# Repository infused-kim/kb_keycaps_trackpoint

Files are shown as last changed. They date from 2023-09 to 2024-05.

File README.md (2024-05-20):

# Scripts to cut TrackPoint holes into keyboard keycaps

These scripts allow you to generate keycaps with a cutout for a TrackPoint.

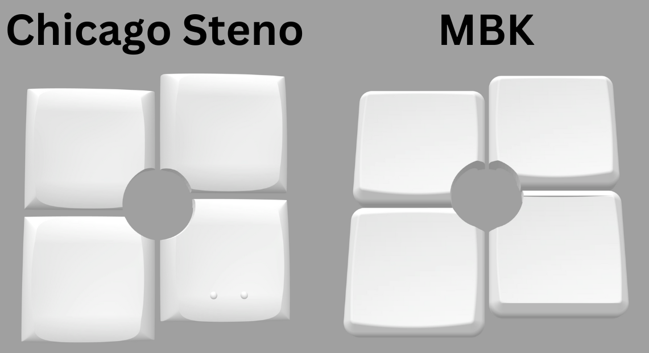
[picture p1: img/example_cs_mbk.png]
Chicago Steno and MBK keycaps with TrackPoint cutout


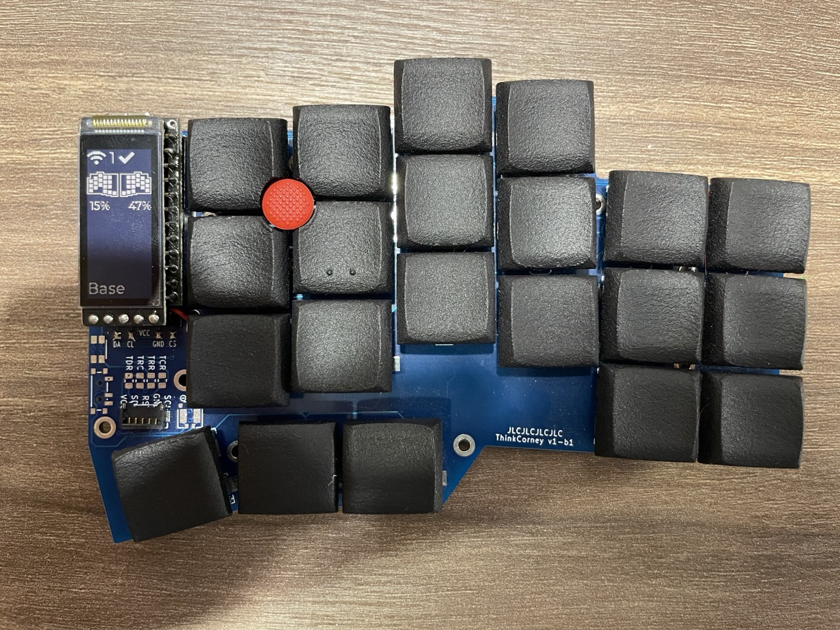
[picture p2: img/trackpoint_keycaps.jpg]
Printed Keycaps


Currently, Chicago Stenographer and MBK keycaps are supported, but it's trivial to add other models as long as you have the stl files.

The generated STLs are sprued and optimized for printing at JLCPCB:

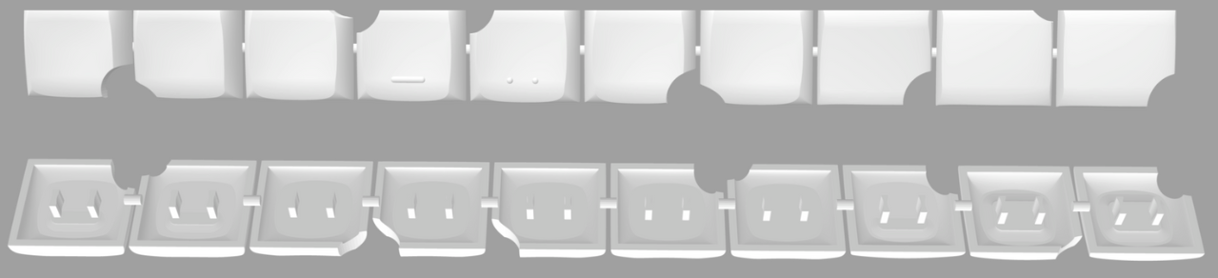
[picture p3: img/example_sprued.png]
Sprued keycaps


This repo was inspired by the awesome idea and work of [wolfwood's printed-keycap-mods](https://github.com/wolfwood/printed-keycap-mods).

However, their code didn't support MBK and is optimized for DIY printing with FDM rather than JLCPCB.

## 1. Table of Contents <!-- omit from toc -->

- [1. Printing / Ordering](#1-printing--ordering)
  - [1.1. How to download the STLs and which files to use](#11-how-to-download-the-stls-and-which-files-to-use)
  - [1.2. How to order on JLCPCB](#12-how-to-order-on-jlcpcb)
  - [1.3. How to print them yourself](#13-how-to-print-them-yourself)
- [2. Using the scripts](#2-using-the-scripts)
  - [2.1. How to generate your own keycaps](#21-how-to-generate-your-own-keycaps)
  - [2.2. How to fix large STL file sizes](#22-how-to-fix-large-stl-file-sizes)
  - [2.3. How to adjust the stagger](#23-how-to-adjust-the-stagger)
  - [2.4. How to adjust the key spacing](#24-how-to-adjust-the-key-spacing)
  - [2.5. How to add a new keycap type](#25-how-to-add-a-new-keycap-type)
- [3. Related Resources \& Projects](#3-related-resources--projects)
- [4. License](#4-license)

## 1. Printing / Ordering

### 1.1. How to download the STLs and which files to use

Go to the [releases section](releases) and download the STL files.

You can find combined STLs that contain all the variations you might need in the `./combined/` folder.

The published files are generated for choc-spaced boards with a stagger of 2.375 (what the corne uses). You can follow the instructions below to generate keycaps with customized spacing and stagger.

Chicago Stenographer has many different variations of keycaps. To understand which ones to use and what the differences are, [check out my fork of those keycaps](https://github.com/infused-kim/kb_keycaps_chicago_stenographer).

There you will also find the rest of the keycaps needed to print a full set or you can buy a full set from the creator [at asymplex.xyz](https://www.asymplex.xyz).

MBK keycaps are not really meant to be printed, so you should buy the rest of the keycaps from one of the many vendors that sell them.

### 1.2. How to order on JLCPCB

* Upload the STL model
* Select 3D Technology: `MJF (Nylon)`
* Select Material: `PA12-HP Nylon`
* Optionally select Surface Finish: `Add - Dyeing - Dyed Black` to get black keycaps.
  * Without this they will be a "textured gray"
* Make sure to select the correct Quantity

The two combined sets should cost $5.05.

### 1.3. How to print them yourself

I have no clue... I don't own a 3D printer and this is my first 3D modeling project.

You can check out [wolfwood's printed-keycap-mods](https://github.com/wolfwood/printed-keycap-mods) as his project is optimized for FDM printing.

You may also find [these instructions](https://www.printables.com/model/158865-chicago-steno-low-profile-ergo-keycaps) valuable.

Perhaps you can modify the files here manually.

I would also be happy to accept a PR that generates STLs that are optimized for printing yourself.

## 2. Using the scripts

### 2.1. How to generate your own keycaps

* Install OpenSCAD
  * The [snapshot version](https://openscad.org/downloads.html#snapshots) is recommended for performance reasons
  * If it crashes, [try an older version of the snapshot](https://files.openscad.org/snapshots/)
* Set up the dev environment
  * Adjust the Makefile with the path to your OpenSCAD installation
* Run the keycap generator
  * Run `make help` to see all available targets
  * Or run `make` to build everything

You can also open the individual files in the OpenSCAD GUI if you prefer.

### 2.2. How to fix large STL file sizes

OpenSCAD generates files with very big sizes and JLCPCB only allows files to be up to 80mb.

To fix this Fusion360 (The free version is fine)...

* Create a new file
  * Do not open the STL directly. That will mess up the units
* Select the `Mesh` tab on the top toolbar
* Select `Insert Mesh` (first icon)
  * Select the STL file and click `Open`
  * This will load the model and show a `Insert Mesh` window
  * Make sure the `Unit Type` is set to `Millimeter`
  * Press the `OK` button
* Save it to the cloud
* Use `File -> Export` to export the file as STL again

The file size should now be under 80 MB.

### 2.3. How to adjust the stagger

You can adjust the stagger by running `make STAGGER=5.5`.

### 2.4. How to adjust the key spacing

By default, keycaps are cut using the choc spacing, but you can change the spacing to mx by running `make PROFILE=mx`.

You can also specify custom values by running `make PROFILE=custom SPREADX=20 SPREADY=22`.

But keep in mind that this doesn't change the size of the keycaps. It only changes the distance at which they are placed before cutting.

### 2.5. How to add a new keycap type

#### 3.5.1. Add the keycap STLs <!-- omit from toc -->

First, add the keycap STLs to the `./keycaps/` directory.

#### 3.5.2. Figure out the positioning offset of the keycaps <!-- omit from toc -->

The cutter expects the keycaps to be centered around the origin, but many keycap designers offset the keys slightly.

You can open the files in Fusion 360 or another 3D editor to figure out the offsets.

#### 3.5.3. Create the SCAD file <!-- omit from toc -->

Then duplicate the `src/gen_mbk.scad` file. Make sure the file name starts with `gen_` or the Makefile won't recognize it.

Adjust the keycap path and add the necessary positional adjustments.

For example, the MBK homing keycap was centered at `x: -23` and `y: 0`. So we moved it to the origin with:

```scad
// Keycap array: stl path, translate adjustment, rotation, mirror
mbk_1u_homing = [
    "../keycaps/mbk/mbk_keycap_1u_homing.stl",  // stl path

    [23, 0, 0],  // translate adjustment / movement
    [0, 0, 0],  // rotation
    [0, 0, 0]  // mirroring
];
```

Check out the [OpenSCAD documentation for translate, rotate, and mirror here](https://en.wikibooks.org/wiki/OpenSCAD_User_Manual/Transformations#rotate) for more information.

#### 3.5.4. Run the script <!-- omit from toc -->

Then just run the cutter with `make name_of_set` or  `make all`.

The name of the target will be the file name of your `.scad` file but without the `gen_` prefix and `.scad` extension.

For example `gen_my_keycap.scad` can be run with `make my_keycap`.

## 3. Related Resources & Projects

- [My TrackPoint Driver for DIY keyboards using the zmk firmware](https://github.com/infused-kim/kb_zmk_ps2_mouse_trackpoint_driver)
- [My TrackPoint Extensions](https://github.com/infused-kim/kb_trackpoint_extension)
- [My Chicago Stenographer Keycap Fork](https://github.com/infused-kim/kb_keycaps_chicago_stenographer)

## 4. License

**TLDR:**

* Personal use with attribution
* Commercial use not allowed

This work is licensed under a
[Creative Commons Attribution-ShareAlike 4.0 International License][cc-by-sa].

[][cc-by-sa]

[cc-by-sa]: http://creativecommons.org/licenses/by-sa/4.0/
[cc-by-sa-image]: https://licensebuttons.net/l/by-sa/4.0/88x31.png
[cc-by-sa-shield]: https://img.shields.io/badge/License-CC%20BY--SA%204.0-lightgrey.svg

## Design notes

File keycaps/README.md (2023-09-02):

# Original keycaps

The files in here are original, uncut keycaps.

## Chicago Stenographer

The popular Chicago Stenographer keycaps in the commonly used variations.

You can find more info on [asymplex.xyz, the creator's homepage where you can order full keysets](https://www.asymplex.xyz).

You can also check [their original github repo](https://github.com/pseudoku/PseudoMakeMeKeyCapProfiles) with the code or my fork with sprued keycaps and JLCPCB printing instructions.

## MBK

These files are a reproduction of the popular MBK keycaps for rendering purposes.They are not the original production files, so printing them will not produce keycaps exactly like production versions.

They are close, but not exact.

Dowloaded from here:
<https://www.thingiverse.com/thing:4564253/files>

One person in the thingiverse comments mentioned that printing them works and that they fit. So it's worth a try.

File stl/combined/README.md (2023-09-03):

# Combined sets

These sets combine all the combination of keys in the most efficient way.

## combined_set_choc_corne_cs_regular_convex.stl

This set contains the regular variations of chicago steno keycaps for both 3-row and 4-row keyboards. It has the top row keys in both R2 and R3 variations.

It also has both variations of the homing key. On top of that it includes all three convex keys.

## combined_set_choc_corne_cs_lateral_mbk.stl

This set contains all chicago steno lateral keycaps for both 3-row and 4-row keyboards. It has the top row keys in both R2 and R3 variations.

On top of that it includes all MBK keycaps.

## Where are the STLs?

To keep the repo small, the stls can be found in the [repo's releases section](../../../../../releases/).

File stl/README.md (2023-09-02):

# Trackpoint Keycap STLs

## About the keycaps

This repo has Chicago Stenographer and MBK keycaps with cutouts for a trackpoint.

To understand how to use the different variations of Chicago Steno, [check my fork of those keycaps](https://github.com/infused-kim/kb_keycaps_chicago_stenographer).

The MBK keycaps are not really meant to be printed, so you should buy the rest of the keycaps at one of the many vendors that sell them.

## Where are the STLs?

To keep the repo small, the stls can be found in the [repo's releases section](../../../releases/).

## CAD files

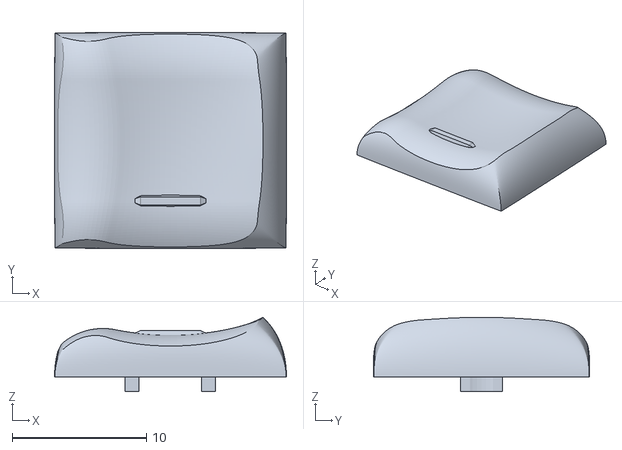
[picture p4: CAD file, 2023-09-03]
keycaps/chicago_steno/cs_r3_lateral_r_bar.stl
17.3 x 16.1 x 5.55

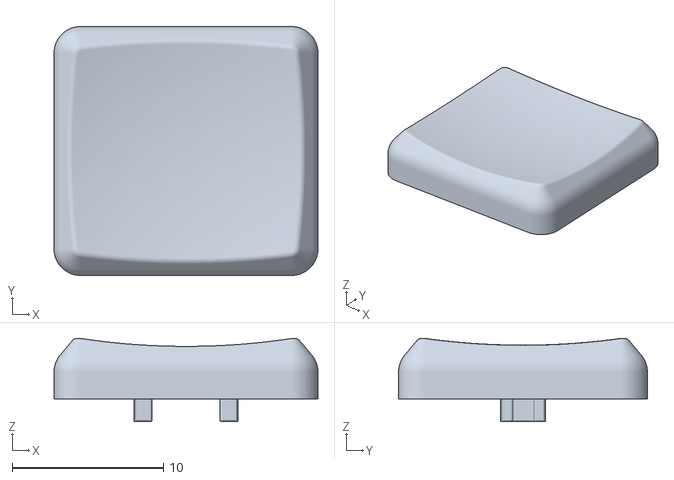
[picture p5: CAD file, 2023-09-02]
keycaps/mbk/mbk_keycap_1u.stl
17.5 x 16.5 x 5.52

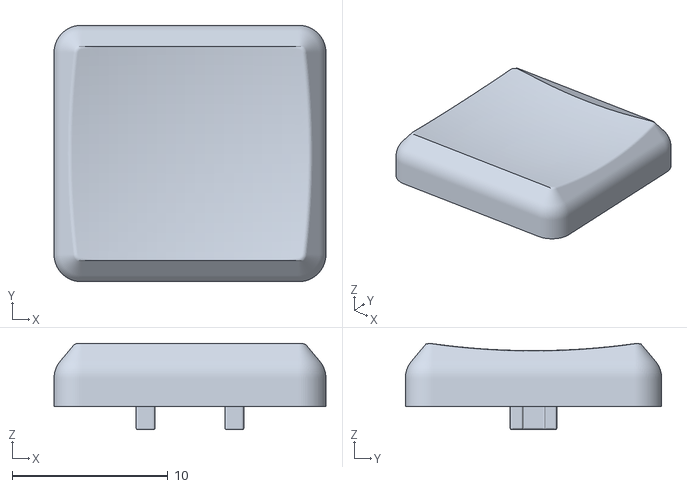
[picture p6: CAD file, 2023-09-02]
keycaps/mbk/mbk_keycap_1u_homing.stl
17.5 x 16.5 x 5.54

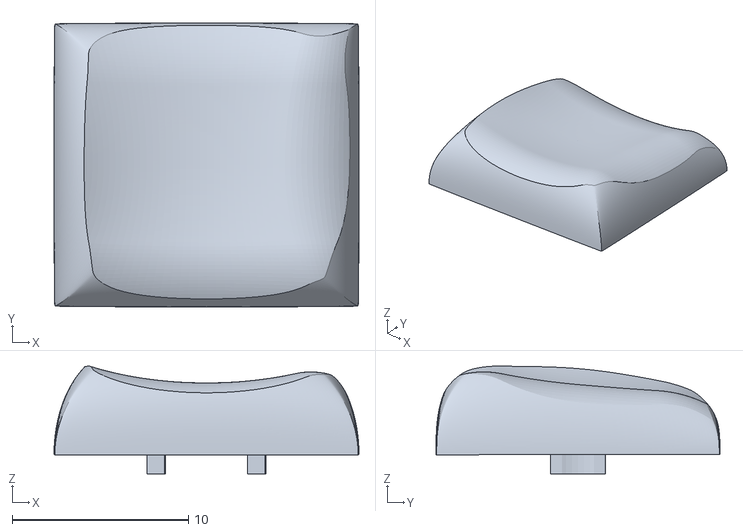
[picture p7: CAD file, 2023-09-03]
keycaps/chicago_steno/cs_r2_lateral_l.stl
17.3 x 16.1 x 6.12

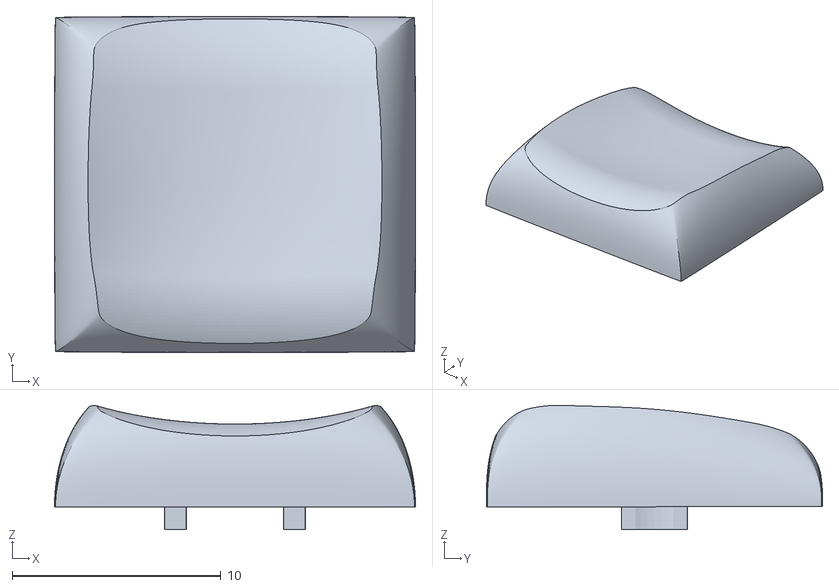
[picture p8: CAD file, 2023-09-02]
keycaps/chicago_steno/cs_r2_1.stl
17.3 x 16.1 x 5.96

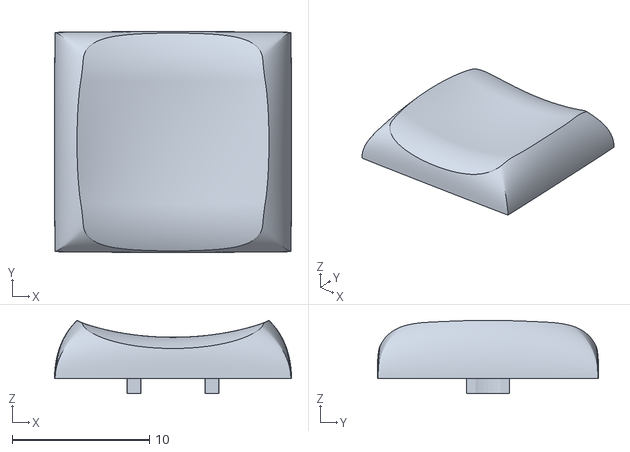
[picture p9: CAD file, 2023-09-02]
keycaps/chicago_steno/cs_r3_1.stl
17.3 x 16.1 x 5.35

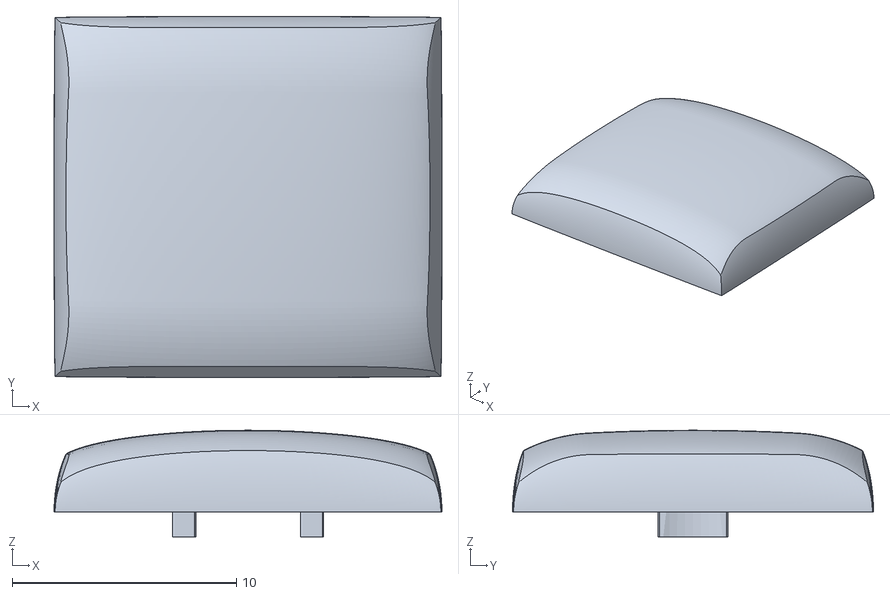
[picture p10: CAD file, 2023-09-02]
keycaps/chicago_steno/cs_r3x_1.stl
17.3 x 16.1 x 4.75

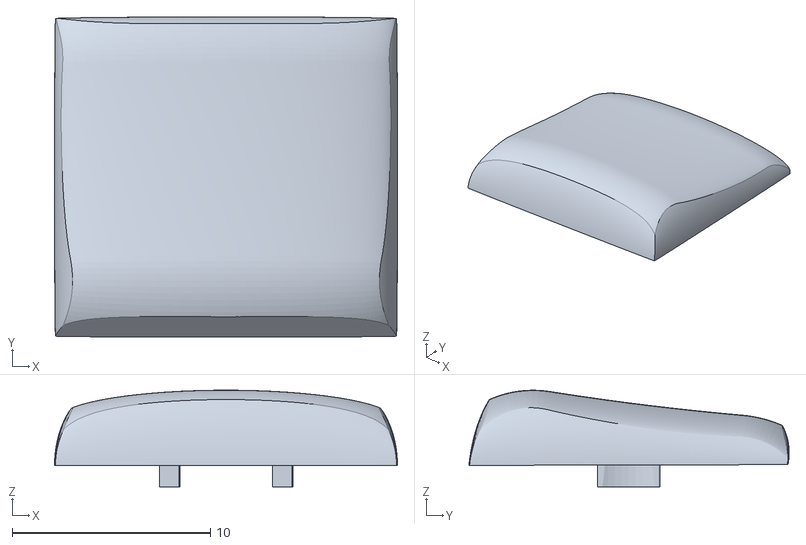
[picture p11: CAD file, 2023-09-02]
keycaps/chicago_steno/cs_r2x_1.stl
17.3 x 16.2 x 4.88

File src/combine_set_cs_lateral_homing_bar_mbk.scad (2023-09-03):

// This set contains all chicago steno lateral keycaps for both 3-row and
// 4-row keyboards. It has the top row keys in both R2 and R3 variations.
//
// On top of that it includes all MBK keycaps.

key_stagger = "corne";
key_profile = "choc";

variation = str(key_profile, "_", key_stagger);

keycaps = [
   // R2R3 Levee
   str("../stl/cs_r2_r3_lateral_homing_bar/cs_r2_r3_lateral_homing_bar_", variation, "_top_left.stl"),
   str("../stl/cs_r2_r3_lateral_homing_bar/cs_r2_r3_lateral_homing_bar_", variation, "_top_right.stl"),
   str("../stl/cs_r2_r3_lateral_homing_bar/cs_r2_r3_lateral_homing_bar_", variation, "_bottom_left.stl"),
   str("../stl/cs_r2_r3_lateral_homing_bar/cs_r2_r3_lateral_homing_bar_", variation, "_bottom_right.stl"),

   // R3 Top Levee
   str("../stl/cs_r3_r3_lateral_homing_bar/cs_r3_r3_lateral_homing_bar_", variation, "_top_left.stl"),
   str("../stl/cs_r3_r3_lateral_homing_bar/cs_r3_r3_lateral_homing_bar_", variation, "_top_right.stl"),

   // MBK
   str("../stl/mbk/mbk_", variation, "_top_left.stl"),
   str("../stl/mbk/mbk_", variation, "_top_right.stl"),
   str("../stl/mbk/mbk_", variation, "_bottom_left.stl"),
   str("../stl/mbk/mbk_", variation, "_bottom_right.stl"),
];

use <stl_combiner.scad>
combine_stl(keycaps);

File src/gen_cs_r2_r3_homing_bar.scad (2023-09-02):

output = "preview";

key_profile = "choc"; // choc, mx or custom while setting key_spread_x and y
key_stagger = "corne"; // Change to numerical value to customize

// Set key_profile to "custom" and then these two parameters if you
// want to use a custom distance between keycaps
key_spread_x = 0;
key_spread_y = 0;

tp_diameter = 9.5; // Most Lenovo trackpoints are 8.5mm wide
tp_height = 14;

// Set to true to draw the trackpoint
debug = false;

use <keycap_cutter.scad>

// The cutter expects keycaps to be centered at origin,
// but the cs keycaps stls are not.
// So here we adjust for that
cs_translate = [0, 18, 0];

// keycap_array_format = [
//    stl_path,
//    translate_adjustment,
//    rotation_adjustment,
//    mirror_adjustment,
// ]
cs_r2_top = [
   "../keycaps/chicago_steno/cs_r2_1.stl",

   // By default the r2 key is rotated for the bottom row
   // here we rotate it for the top row
   cs_translate, [0, 0, 180], [0, 0, 0]
];
cs_r3 = [
   "../keycaps/chicago_steno/cs_r3_1.stl",
   cs_translate, [0, 0, 0], [0, 0, 0]
];
cs_r3_bar = [
   "../keycaps/chicago_steno/cs_r3_1_bar.stl",
   cs_translate, [0, 0, 0], [0, 0, 0]
];

cut_keycaps(
   keycap_top_left=cs_r2_top,
   keycap_top_right=cs_r2_top,
   keycap_bottom_left=cs_r3,
   keycap_bottom_right=cs_r3_bar,
   output,
   key_profile,
   key_stagger,
   key_spread_x,
   key_spread_y,
   tp_diameter,
   tp_height,
   debug
);

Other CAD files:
keycaps/chicago_steno/cs_r3_lateral_r_dot.stl
keycaps/chicago_steno/cs_r3_lateral_l.stl
keycaps/chicago_steno/cs_r3_1_dot.stl
keycaps/chicago_steno/cs_r3_1_bar.stl
src/combine_set_cs_lateral_homing_dot_mbk.scad
src/gen_cs_r2_r3_homing_bar_convex.scad
src/combine_set_1.scad
src/combine_set_2.scad
src/combine_set_cs_regular_convex.scad
src/cs_keys.scad
src/gen_cs_r2_r3_homing_dot.scad
src/gen_cs_r2_r3_lateral_homing_bar.scad
src/gen_cs_r2_r3_lateral_homing_dot.scad
src/gen_cs_r2_r3_levee.scad
src/gen_cs_r3_r3_homing_bar.scad
src/gen_cs_r3_r3_homing_bar_convex.scad
src/gen_cs_r3_r3_homing_dot.scad
src/gen_cs_r3_r3_homing_dot_convex.scad
src/gen_cs_r3_r3_lateral_homing_bar.scad
src/gen_cs_r3_r3_lateral_homing_dot.scad
src/gen_cs_r3_r3_levee.scad
src/gen_mbk.scad
src/keycap_cutter.scad
src/stl_combiner.scad

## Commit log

2023-09-02 Added initial version for mbk keycaps
    [keycap_cutter.scad, mbk_keycap_1u.stl]
2023-09-02 Added all source keycaps
    [cs_r2_1.stl, cs_r2_levee_l.stl, cs_r2x_1.stl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]
2023-09-02 Moved keycap settings into separte files
    [gen_cs_r2_r3_homing_bar.scad, gen_mbk.scad, keycap_cutter.scad]
2023-09-02 Created Makefile
    [gen_cs_r2_r3_homing_bar.scad, gen_mbk.scad, keycap_cutter.scad]
2023-09-02 Center final keycaps around origin
    [keycap_cutter.scad]
2023-09-02 Added ability to generate sprued files
    [keycap_cutter.scad, stl_combiner.scad]
2023-09-02 Fix incorrect stagger calculation
    [keycap_cutter.scad]
2023-09-02 Added all chicago steno variations
    [cs_keys.scad, gen_cs_r2_r3_homing_bar_convex.scad, gen_cs_r2_r3_homing_dot.scad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]
2023-09-02 Ignore stl dir
2023-09-02 Added combined sets
    [combine_set_1.scad, combine_set_2.scad, xgen_spru_mbk.scad]
2023-09-02 Replace levee homing key with proper 2-dot version
    [cs_keys.scad, cs_r3_levee_l_dot.stl, cs_r3_levee_r_dot.stl]
2023-09-03 Renamed combined sets
    [combine_set_cs_lateral_mbk.scad, combine_set_cs_regular_convex.scad]
2023-09-03 Fixed cs lateral homing dots to be the same as regular keycaps and renamed from levee
    [combine_set_cs_lateral_mbk.scad, cs_keys.scad, cs_r2_lateral_l.stl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]
2023-09-03 Added cs lateral with homing bar
    [combine_set_cs_lateral_homing_bar_mbk.scad, combine_set_cs_lateral_homing_dot_mbk.scad, cs_keys.scad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]
